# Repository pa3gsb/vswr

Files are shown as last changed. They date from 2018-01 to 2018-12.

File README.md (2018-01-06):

VSWR - Module
==============================================

## Project:

For the radioberry this module gives the possibility for getting information about the vswr during transmit.

The module contains the possibility to measure the REF and FORWARD power.

Using a low speed i2c module makes it possible to read the data using the raspberry pi.

I have plans to add the reading:

-) to a seperate program to showing the measured data.
-) in the hpsdr emulator
-) in the pihpsdr plugin. 

Something about the setup.

The original design appeared in 1989 / 1990 SPRAT Magazine G-QRP
Also in the famous dutch QRP nieuwsbrief (NB 62) if found the article: "SWR METER ZONDER AFREGELING" door PAoWDW
I found it also in the openhpsdr ALEX project.

I did add the slow ADC i2c (as seen in the hermeslite version 2 design) 

## KICAD
Used KICAD to make the scheme and PCB.

Beside all this iam learning KICAD (stepped over from EAGLE). 
I like the KICAD program, much to learn, used start drawing a scheme. 
Add footprints and creating a PCB.

## Ordering
I ordered 6 January 2018 10 pcb at elecrow.

In the Netherlands it is possible to order at https://muxtronics.nl/ the components using the ShopCart from farnell.

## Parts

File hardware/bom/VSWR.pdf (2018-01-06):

## VSWR Module beta1 BOM

Assembly Build - January 1, 2018

Part ID | Description | Part Number | Sub OK | Designators | Footprint | Pins | Quantity
| 100nF 0805≥X7R≥25V≤10% | C0805C104K3RACTU (http://www.octopart.com/search?q=C0805C104K3RACTU) | Y | C1,C2,C3,C8,C9,C10 | 0805 | 2 | 6
| 100uF 0805≥X5R≥6.3V≤20% | GRM32ER60J107ME20L (http://www.octopart.com/search?q=GRM32ER60J107ME20L) | Y | C4 | 0805 | 2 | 1
| 10nF 0805≥X5R≥6.3V≤20% | C0805C103K5RACTU (http://www.octopart.com/search?q=C0805C103K5RACTU) | Y | C5,C6,C7 | 0805 | 2 | 3
| Schottky Barrier Diode | 1N5711WS-7-F (http://www.octopart.com/search?q=1N5711WS-7-F) | N | D1,D2,D3,D4 | SOD-323 | 2 | 4
| IC REG LINEAR 3.3V 800MA | NCP1117ST33T3G (http://www.octopart.com/search?q=NCP1117ST33T3G) | Y | IC1 | SOT223 | 4 | 1
| 51.1 | MCPWR10FTEQ0510 (http://www.octopart.com/search?q=MCPWR10FTEQ0510) | N | R1,R2 | 2010 | 2 | 2
| 100K | CRCW0805100KFKEA (http://www.octopart.com/search?q=CRCW0805100KFKEA) | Y | R3,R4 | 0805 | 2 | 2
| 220K | RCV0805220KFKEA (http://www.octopart.com/search?q=RCV0805220KFKEA) | Y | R5,R6 | 0805 | 2 | 2
| 1K | CRCW08051K00FKEA (http://www.octopart.com/search?q=CRCW08051K00FKEA) | Y | R7,R8 | 0805 | 2 | 2
| 1K8 | CRCW08051K80FKEA (http://www.octopart.com/search?q=CRCW08051K80FKEA) | Y | R9,R10 | 0805 | 2 | 2
| FT-50-43 | Amidon (http://www.octopart.com/search?q=Amidon) | N | T1,T2 | Custom | 4 | 2
| General Purpose Amplifier 2 Circuit Rail-to-Rail | LMC6482AIM (http://www.octopart.com/search?q=LMC6482AIM) | N | U1 | SOIC-8 | 8 | 1
| Slow ADC | MAX11613EUA (http://www.octopart.com/search?q=MAX11613EUA) | N | U3 | 8-MSOP (3.00mm) | 8 | 1

Line Items: SMT:12 Assembled TH:1 Parts: SMT:27 Assembled TH:2 Pins: SMT:68 Assembled TH:8
Do Not Assemble: J1 J2 J3 R11 R12

1

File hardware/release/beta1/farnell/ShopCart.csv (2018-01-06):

Artikelnr. | Ordercode | RoHS-compatibel? | Opmerkingen | Hoeveelheid | Artikelnummer fabrikant | Naam fabrikant | Fabrikant / beschrijving | Beschikbaarheid | Prijs per stuk | Artikelprijs | Prijs na korting
1 | 1650863 | YES |  | 10.0 | C0805C104K3RACTU | KEMET | Ceramic Capacitor Case:0805 [2012 Metric]; Capacitance:0.1µF; Voltage Rating:25V; Capacitance Tolerance:± 10%; Dielectric Characteristic:X7R; Product Range:C Series; Packaging:Cut Tape; | 53653 | 0.0654 | 0.65
2 | 1828817 | YES |  | 1.0 | GRM32ER60J107ME20L | MURATA | Ceramic Capacitor Case:1210 [3225 Metric]; Capacitance:100µF; Voltage Rating:6.3V; Capacitance Tolerance:± 20%; Dielectric Characteristic:X5R; Product Range:GRM Series; Packaging:Cut Ta | 2093 | 0.8380 | 0.84
3 | 1414662 | YES |  | 10.0 | C0805C103K5RACTU | KEMET | Ceramic Capacitor Case:0805 [2012 Metric]; Capacitance:0.01µF; Voltage Rating:50V; Capacitance Tolerance:± 10%; Dielectric Characteristic:X7R; Product Range:C Series; Packaging:Cut Tape; | 478462 | 0.0446 | 0.45
4 | 1843765 | YES |  | 5.0 | 1N5711WS-7-F | DIODES INC. | Diode Configuration:Single; Repetitive Reverse Voltage Vrrm Max:70V; Forward Current If(AV):15mA; Forward Voltage VF Max:1V; Forward Surge Current Ifsm Max:-; Operating Temperature Ma | 3554 | 0.5710 | 2.86
5 | 1469860 | Y-EX |  | 10.0 | CRCW0805100KFKEA | VISHAY | Resistance:100kohm; Voltage Rating:150V; Resistor Element Material:Thick Film; Resistor Case Style:0805 [2012 Metric]; Power Rating:125mW; Resistance Tolerance:± 1%; Product Range | 97981 | 0.0619 | 0.62
6 | 2352622 | Y-EX |  | 10.0 | RCV0805220KFKEA | VISHAY | Resistance:220kohm; Voltage Rating:400V; Resistor Element Material:Thick Film; Resistor Case Style:0805 [2012 Metric]; Power Rating:125mW; Resistance Tolerance:± 1%; Product Range | 2800 | 0.1590 | 1.59
7 | 1469847 | Y-EX |  | 10.0 | CRCW08051K00FKEA | VISHAY | Resistance:1kohm; Voltage Rating:150V; Resistor Element Material:Thick Film; Resistor Case Style:0805 [2012 Metric]; Power Rating:125mW; Resistance Tolerance:± 1%; Product Range:CRC | 171151 | 0.0619 | 0.62
8 | 1652943 | Y-EX |  | 10.0 | CRCW08051K80FKEA | VISHAY | Resistance:1.8kohm; Voltage Rating:150V; Resistor Element Material:Thick Film; Resistor Case Style:0805 [2012 Metric]; Power Rating:125mW; Resistance Tolerance:± 1%; Product Range: | 44310 | 0.0557 | 0.56
9 | 2764704 | YES |  | 1.0 | LMC6482AIMX/NOPB | TEXAS INSTRUMENTS | No. of Amplifiers:2 Amplifier; Bandwidth:1.5MHz; Slew Rate:1.3V/µs; Supply Voltage Range:3V to 15.5V; Amplifier Case Style:SOIC; No. of Pins:8Pins; Operating Temperature Min:-40°C; Operat | 350 | 1.8700 | 1.87
10 | 2513418 | YES |  | 1.0 | MAX11613EUA+ | MAXIM INTEGRATED PRODUCTS | Resolution (Bits):12bit; Sampling Rate:94.4kSPS; Supply Voltage Type:Single; Supply Voltage Min:2.7V; Supply Voltage Max:3.6V; ADC / DAC Case Style:µMAX; No. of Pins:8Pins; Input | 62 | 2.2200 | 2.22
11 | 1887585 | Y-EX |  | 10.0 | MCPWR10FTEQ0510 | MULTICOMP | Resistance:51ohm; Voltage Rating:400V; Resistor Element Material:Thick Film; Resistor Case Style:2010 [5025 Metric]; Power Rating:750mW; Resistance Tolerance:± 1%; Product Range:MCP | 3235 | 0.2460 | 2.46
12 | 1652366 | YES |  | 1.0 | NCP1117ST33T3G | ON SEMICONDUCTOR | Output Type:Fixed; Input Voltage Min:3.5V; Input Voltage Max:20V; Fixed Output Voltage Nom.:3.3V; Adjustable Output Voltage Min:-; Adjustable Output Voltage Max:-; Output Current:1A; Dropout | 16 | 0.4760 | 0.48
13 | 2096223 | YES |  | 2.0 | SMA CONNECTOR | LPRS | Connector Type:SMA Coaxial; Connector Body Style:-; Coaxial Termination:Solder; Impedance:-; Coaxial Cable Types:-; Contact Material:-; Contact Plating:-; Frequency Max:-; Connector Mounting:PCB | 3609 | 0.9240 | 1.85
 |  |  |  |  |  |  | Subtotaal | 17.05
 |  |  |  |  |  |  | Totaal aantal goederen | 17.05
 |  |  |  |  |  |  | Standaard | 0.00
 |  |  |  |  |  |  | BTW | Onbekend
 |  |  |  |  |  |  | Totaal | 17.05

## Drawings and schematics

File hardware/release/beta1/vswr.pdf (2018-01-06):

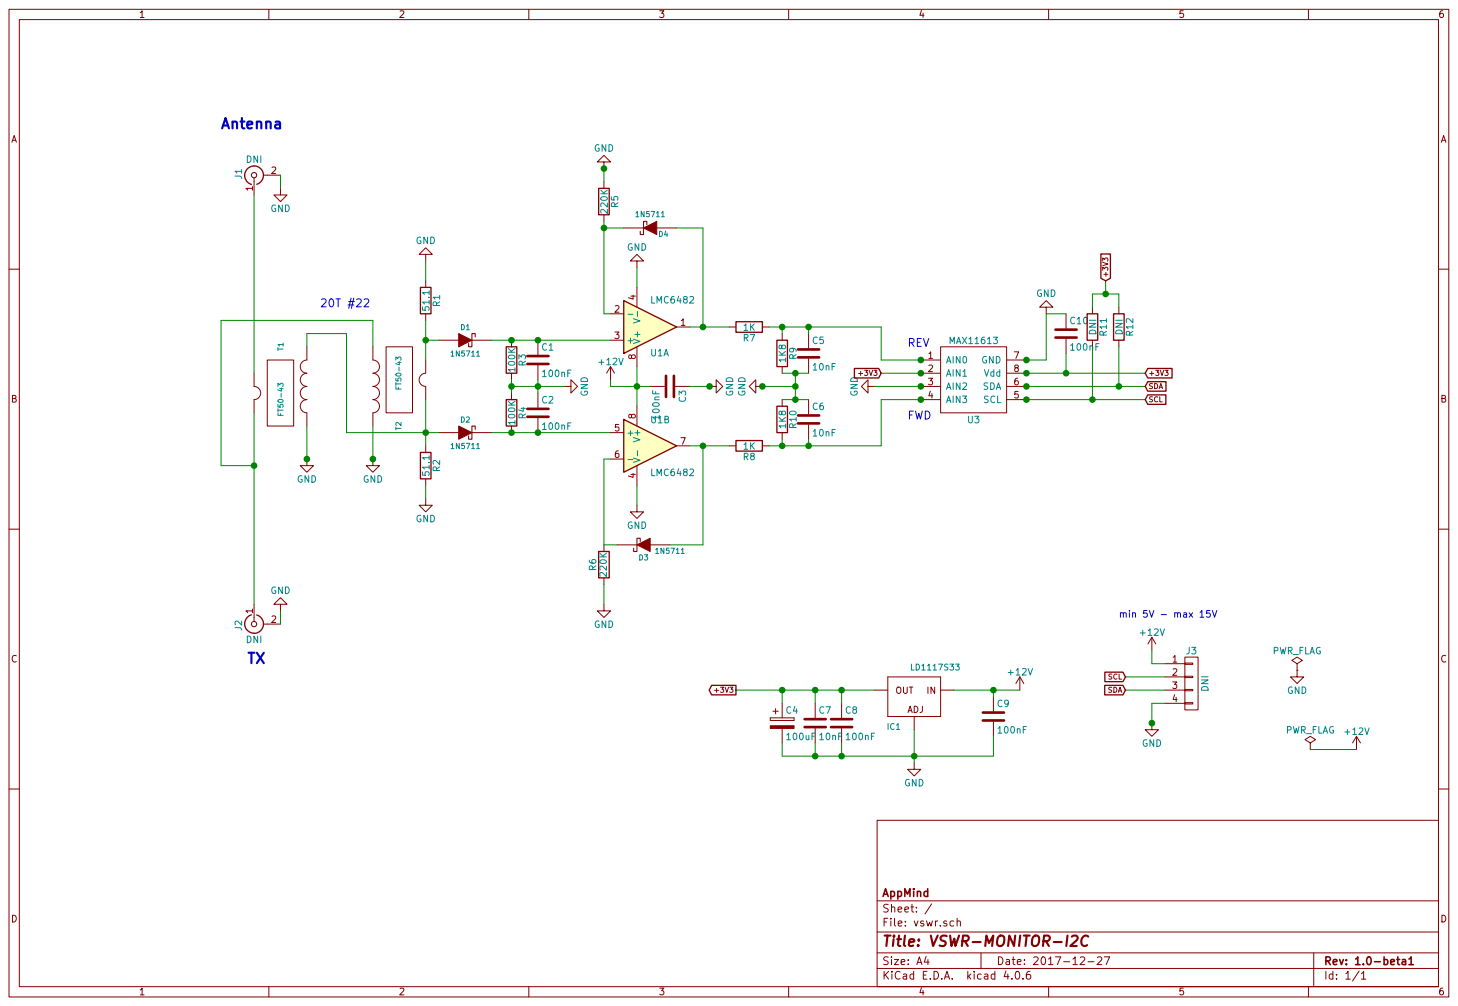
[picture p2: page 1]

Id: 1/1 Title: VSWR-MONITOR-I2C

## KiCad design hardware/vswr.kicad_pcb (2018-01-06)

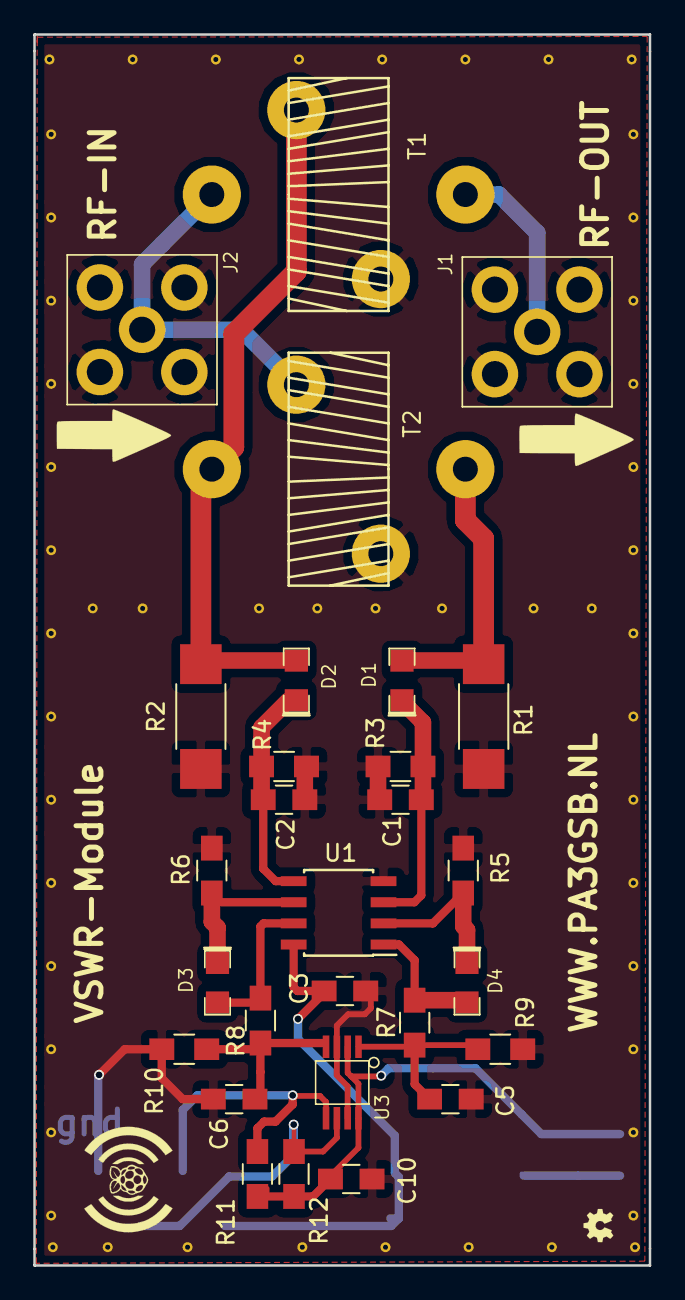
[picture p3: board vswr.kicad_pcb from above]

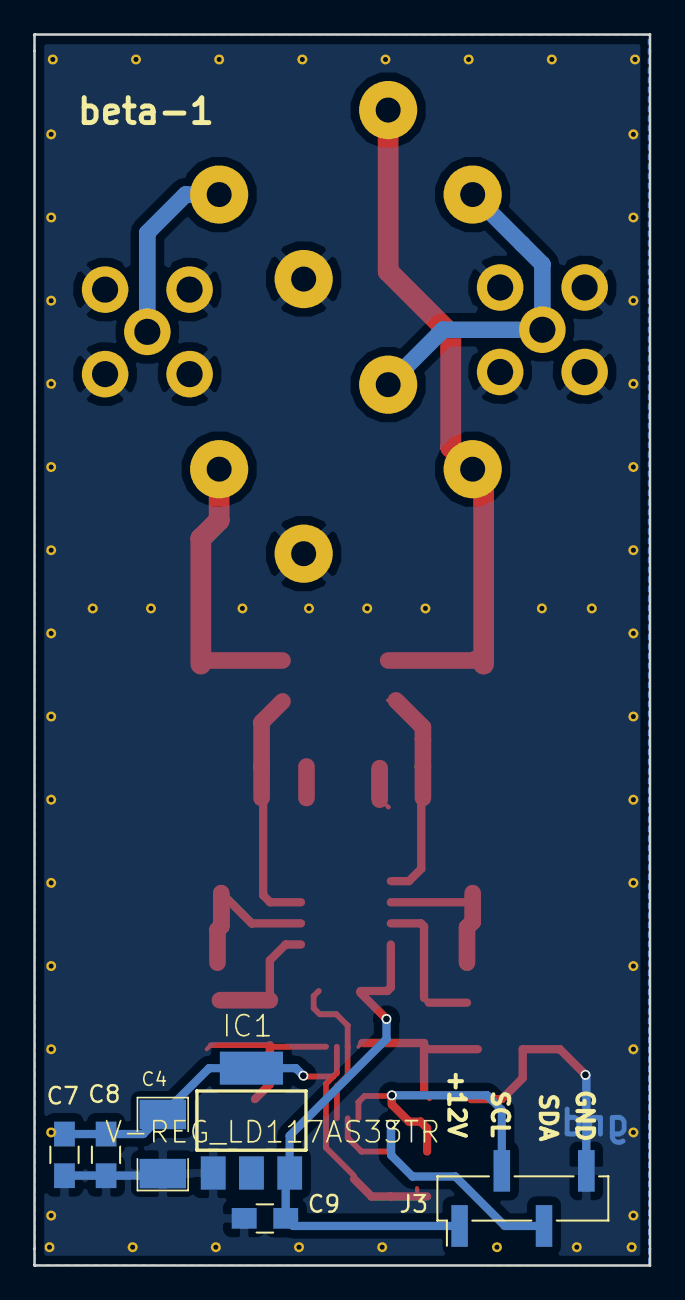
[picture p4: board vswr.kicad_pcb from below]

Board: 2 copper layers, 37.0 x 74.0 mm, 34 parts (6 on the bottom side), 17 nets.

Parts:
C1, C2, C3, C10: 100nF; C_0805_HandSoldering
C4: CP; SMD-1210
C5, C6: 10nF; C_0805_HandSoldering
C7, C8, C9: C; C_0805_HandSoldering
D1, D2, D3, D4: 1N5711W-7-F; 1N5711WS
IC1: V-REG_LD117AS33TR; V-REG_SOT223
J1, J2: CONN_COAXIAL; SMAVERT
J3: CONN_01X04; Pin_Header_Straight_1x04_Pitch2.54mm_SMD_Pin1Left
R1, R2: 51.1; R_2010_HandSoldering
R3, R4: 100K; R_0805_HandSoldering
R5, R6: 220K; R_0805_HandSoldering
R7, R8: 1K; R_0805_HandSoldering
R9, R10: 1K8; R_0805_HandSoldering
R11, R12: 4K7; R_0805_HandSoldering
T1, T2: FT50-43; T50-43_V_THT
U1: LMC6482; SOIC-8_3.9x4.9mm_Pitch1.27mm
U3: MAX11613

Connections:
+3V3: C4.1, C7.1, C8.1, C10.2, IC1.4, R11.1, R12.1, U3.2, U3.8
+12V: C3.2, C9.1, IC1.3, J3.1, U1.8
GND: C1.2, C2.1, C3.1, C4.2, C5.2, C6.1, C7.2, C8.2, C9.2, C10.1, IC1.1, J1.2, J2.2, J3.4, R1.1, R2.2, R3.2, R4.1, R5.1, R6.1, R9.2, R10.1, T1.3, T2.4, U1.4, U3.3, U3.7
unnamed: C1.1, D1.2, R3.1, U1.3
unnamed: C2.2, D2.2, R4.2, U1.5
unnamed: C5.1, R7.1, R9.1, U3.1
unnamed: C6.2, R8.1, R10.2, U3.4
unnamed: D1.1, R1.2, T2.1
unnamed: D2.1, R2.1, T1.4, T2.2
unnamed: D3.1, R8.2, U1.7
unnamed: D3.2, R6.2, U1.6
unnamed: D4.1, R7.2, U1.1
unnamed: D4.2, R5.2, U1.2
unnamed: J1.1, T1.2
unnamed: J2.1, T1.1, T2.3
SCL: J3.2, R11.2, U3.5
SDA: J3.3, R12.2, U3.6

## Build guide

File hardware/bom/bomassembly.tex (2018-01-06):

\documentclass{article} 
\usepackage[english]{babel}
\usepackage[bookmarks=false]{hyperref}
\usepackage{pdflscape}
\usepackage{xcolor}
\usepackage{longtable}
\usepackage[T1]{fontenc}
\hypersetup{
    colorlinks,
    linkcolor={red!50!black},
    citecolor={blue!50!black},
    urlcolor={blue!80!black}
}
\usepackage[letterpaper, landscape, left=1.3cm, right=1.3cm, top=2cm, bottom=2.5cm]{geometry}

\begin{document}

\input{bompre.dat}

\begin{center}
    \begin{longtable}{| r | p{4.7cm} | l | l | p{3.8cm} | l | r | r |}
    \hline
	\multicolumn{1}{|l|}{\textbf{Part ID}} & \multicolumn{1}{l|}{\textbf{Description}} & \multicolumn{1}{l|}{\textbf{Part Number}} & \multicolumn{1}{l|}{\textbf{Sub OK}} & \multicolumn{1}{l|}{\textbf{Designators}} & \multicolumn{1}{l|}{\textbf{Footprint}} & \multicolumn{1}{r|}{\textbf{Pins}} & \multicolumn{1}{r|}{\textbf{Quantity}} \\ \hline	 
	\endhead
	\input{bom.dat}
    \end{longtable}
\end{center}

\input{bompost.dat}

\end{document}

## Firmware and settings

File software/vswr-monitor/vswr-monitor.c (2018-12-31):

#include <gtk/gtk.h>
#include <cairo.h>
#include <pigpio.h>
#include <unistd.h>

#include "meter.h"

#define MAX_DISPLAY_WIDTH  400
#define MAX_DISPLAY_HEIGHT 120

#define METER_WIDTH (400)
#define METER_HEIGHT (120)

GtkWidget *top_window;
GtkWidget *fixed;
GtkWidget *canvas;
GtkWidget *grid;
GtkWidget *parent_window;
GtkWidget *meter;
gint display_width;
gint display_height;
gint full_screen;


#define MAX11613_ADDRESS	0x34		
unsigned char data[8];
unsigned int i2c_bus;
int i2c_handler = 0;


int initI2C() {
	if (gpioInitialise() < 0) {
		fprintf(stderr,"gpio could not be initialized. \n");
		return -1;
	}
	
	i2c_bus = 1;
	i2c_handler = i2cOpen(i2c_bus, MAX11613_ADDRESS, 0);
	
	if (i2c_handler < 0)  return -1;
	
	unsigned char config[1];
	config[0] = 0x07;
	int writeResult = i2cWriteDevice(i2c_handler, config, 1);
	if (writeResult != 0 ) {
		printf ("adc config error");
		return -1;
	}
}

gboolean main_delete (GtkWidget *widget) {
	
	i2cClose(i2c_handler);
	gpioTerminate();
	
	_exit(0);
}

int update_meter(void *dummy) {
	
	int result = i2cReadDevice(i2c_handler, data, 8);
	int rev = (int)(((data[0] & 0x0F) <<8) | data[1]);
	int fwv = (int)(((data[6]&0x0F)<<8) | data[7]);

	double constant1=3.3;	//reference voltage
	double constant2=0.09;	//bridge voltage
	double v1;
	v1=((double)fwv/4095.0)*constant1;
	double fw_pwr=(v1*v1)/constant2;

	double rev_pwr = 0.0;
	v1=((double)rev/4095.0)*constant1;
	rev_pwr=(v1*v1)/constant2;

	meter_update(fw_pwr, rev_pwr);
	
	return TRUE;
}

static void activate (GtkApplication *app, gpointer user_data)
{
  top_window = gtk_application_window_new (app);
  gtk_widget_set_size_request(top_window, MAX_DISPLAY_WIDTH, MAX_DISPLAY_HEIGHT);
  gtk_window_set_title (GTK_WINDOW (top_window), "VSWR Monitor");
  gtk_window_set_position(GTK_WINDOW(top_window),GTK_WIN_POS_CENTER_ALWAYS);
  gtk_window_set_resizable(GTK_WINDOW(top_window), FALSE);
  
  g_signal_connect (top_window, "delete-event", G_CALLBACK (main_delete), NULL);
  
  grid = gtk_grid_new();
  gtk_widget_set_size_request(grid, MAX_DISPLAY_WIDTH, MAX_DISPLAY_HEIGHT);
  gtk_grid_set_row_homogeneous(GTK_GRID(grid),FALSE);
  gtk_grid_set_column_homogeneous(GTK_GRID(grid),FALSE);
  gtk_container_add (GTK_CONTAINER (top_window), grid);
  
  gtk_widget_show_all(top_window);
  
  gtk_window_set_title (GTK_WINDOW (top_window), "VSWR-MONITOR");
  
  fixed=gtk_fixed_new();
  gtk_container_remove(GTK_CONTAINER(top_window),grid);
  gtk_container_add(GTK_CONTAINER(top_window), fixed);
  
  meter = meter_init(METER_WIDTH,METER_HEIGHT,top_window);
  gtk_fixed_put(GTK_FIXED(fixed),meter,0,0);
  
  gtk_widget_show_all (fixed);

  gdk_threads_add_timeout_full(G_PRIORITY_HIGH_IDLE,10, update_meter, NULL, NULL);
  
  gdk_window_set_cursor(gtk_widget_get_window(top_window),gdk_cursor_new(GDK_ARROW));

}

int main (int argc, char **argv)
{
	if (initI2C() < 0) return -1;	
	
	GtkApplication *app;
	int status;
	app = gtk_application_new ("org.gtk.example", G_APPLICATION_FLAGS_NONE);
	g_signal_connect (app, "activate", G_CALLBACK (activate), NULL);
	status = g_application_run (G_APPLICATION (app), argc, argv);
	g_object_unref (app);
	
	return status;
}

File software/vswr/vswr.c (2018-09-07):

/*
      	VSWR
		
		Reading ....
	  
	2018 Johan PA3GSB
*/

#include <stdlib.h>
#include <stdio.h>
#include <pigpio.h>
#include <unistd.h>

#define MAX11613_ADDRESS	0x34		

unsigned char data[8];
unsigned int i2c_bus;

int main(int argc, char **argv)
{
	int i2c_handler = 0;
	
	if (gpioInitialise() < 0) {
		fprintf(stderr,"gpio could not be initialized. \n");
		exit(-1);
	}
	
	i2c_bus = 1;
	i2c_handler = i2cOpen(i2c_bus, MAX11613_ADDRESS, 0);
	
	if (i2c_handler < 0)  return -1;
	
	unsigned char config[1];
	config[0] = 0x07;
	int writeResult = i2cWriteDevice(i2c_handler, config, 1);
	if (writeResult != 0 ) {
		printf ("adc config error");
		return -1;
	}

	while (1) {

		int result = i2cReadDevice(i2c_handler, data, 8);
		int rev = (int)(((data[0] & 0x0F) <<8) | data[1]);
		printf("data AIN0 (rev) = %d \n", rev);

		//sample = (int)(((data[2]&0x0F)<<8)  | data[3]);
		//printf("data AIN1 = %d \n", sample);
		
		//sample = (int)(((data[4]&0x0F)<<8) | data[5]);
		//printf("data AIN2 = %d \n", sample);
		
		int fwv = (int)(((data[6]&0x0F)<<8) | data[7]);
		printf("data AIN3 (fwv) = %d \n", fwv);
		

		printf("\n\n");
		
		double constant1=3.3;	//reference voltage
        double constant2=0.09;	//bridge voltage
		double v1;
		v1=((double)fwv/4095.0)*constant1;
		double fw_pwr=(v1*v1)/constant2;
		
		printf("forward pwr = %f \n", fw_pwr);

		double rev_pwr = 0.0;
		
		v1=((double)rev/4095.0)*constant1;
		rev_pwr=(v1*v1)/constant2;
		
		printf("rev pwr = %f \n", rev_pwr);
		
		double swr=(fw_pwr+rev_pwr)/(fw_pwr-rev_pwr);
		if(swr<0.0) swr=1.0;
		printf("SWR: %1.1f:1",swr);
		
		printf("\n\n");
		
		sleep (1);
	}
		
	i2cClose(i2c_handler);
	gpioTerminate();
}
